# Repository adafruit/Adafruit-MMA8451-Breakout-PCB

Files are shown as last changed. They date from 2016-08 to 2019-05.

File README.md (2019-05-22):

## Adafruit MMA8451 Triple-Axis Accelerometer - ±2/4/8g @ 14-bit Breakout PCB
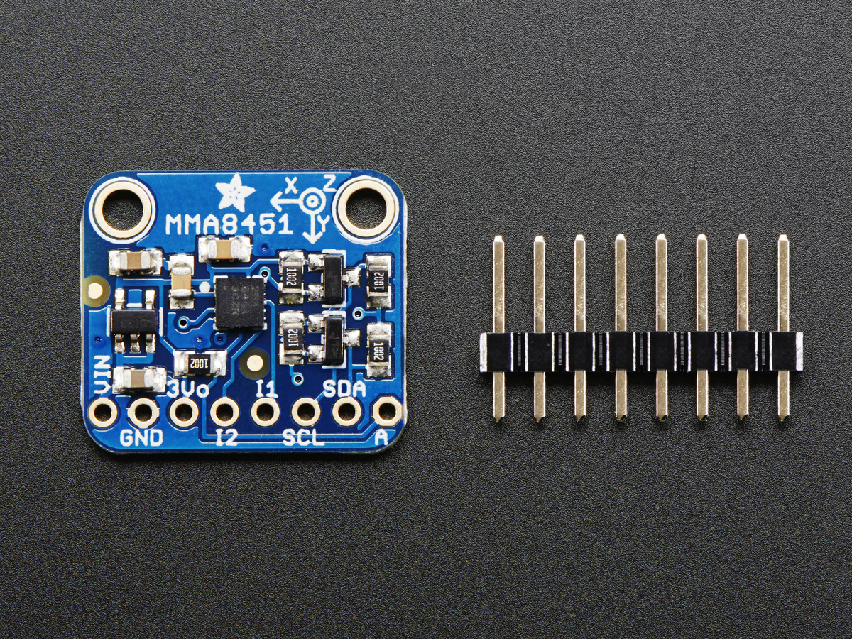
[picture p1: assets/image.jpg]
<a href="http://www.adafruit.com/products/2019"><br/>
Click here to purchase one from the Adafruit shop</a>

So many accelerometers and so little time! We've expanded our accelerometer selection even more with this high-precision and inexpensive MMA8451 Triple-Axis Accelerometer w/ 14-bit ADC. You can detect motion, tilt and basic orientation with a digital accelerometer - and the MMA8451 is a great accelerometer to start with. It has a wide usage range, from +-2g up to +-8g yet is easy to use with Arduino or another microcontroller

The MMA8451 is a miniature little accelerometer from Freescale, who are (by this point) masters at the accelerometer-design game. It's designed for use in phones, tablets, smart watches, and more, but works just as well in your Arduino project. Of the MMA8451/MMA8452/MMA8453 family, the MMA8451 is the most precise with a built in 14-bit ADC. The accelerometer also has built in tilt/orientation detection so it can tell you whether your project is being held in landscape or portrait mode, and whether it is tilted forward or back

PCB files for the Adafruit MMA8451 Breakout. The format is EagleCAD schematic and board layout
- https://www.adafruit.com/product/2019

### License

Adafruit invests time and resources providing this open source design, please support Adafruit and open-source hardware by purchasing products from [Adafruit](https://www.adafruit.com)!

All text above must be included in any redistribution

Designed by Limor Fried/Ladyada for Adafruit Industries.
Creative Commons Attribution/Share-Alike, all text above must be included in any redistribution. 
See license.txt for additional information.

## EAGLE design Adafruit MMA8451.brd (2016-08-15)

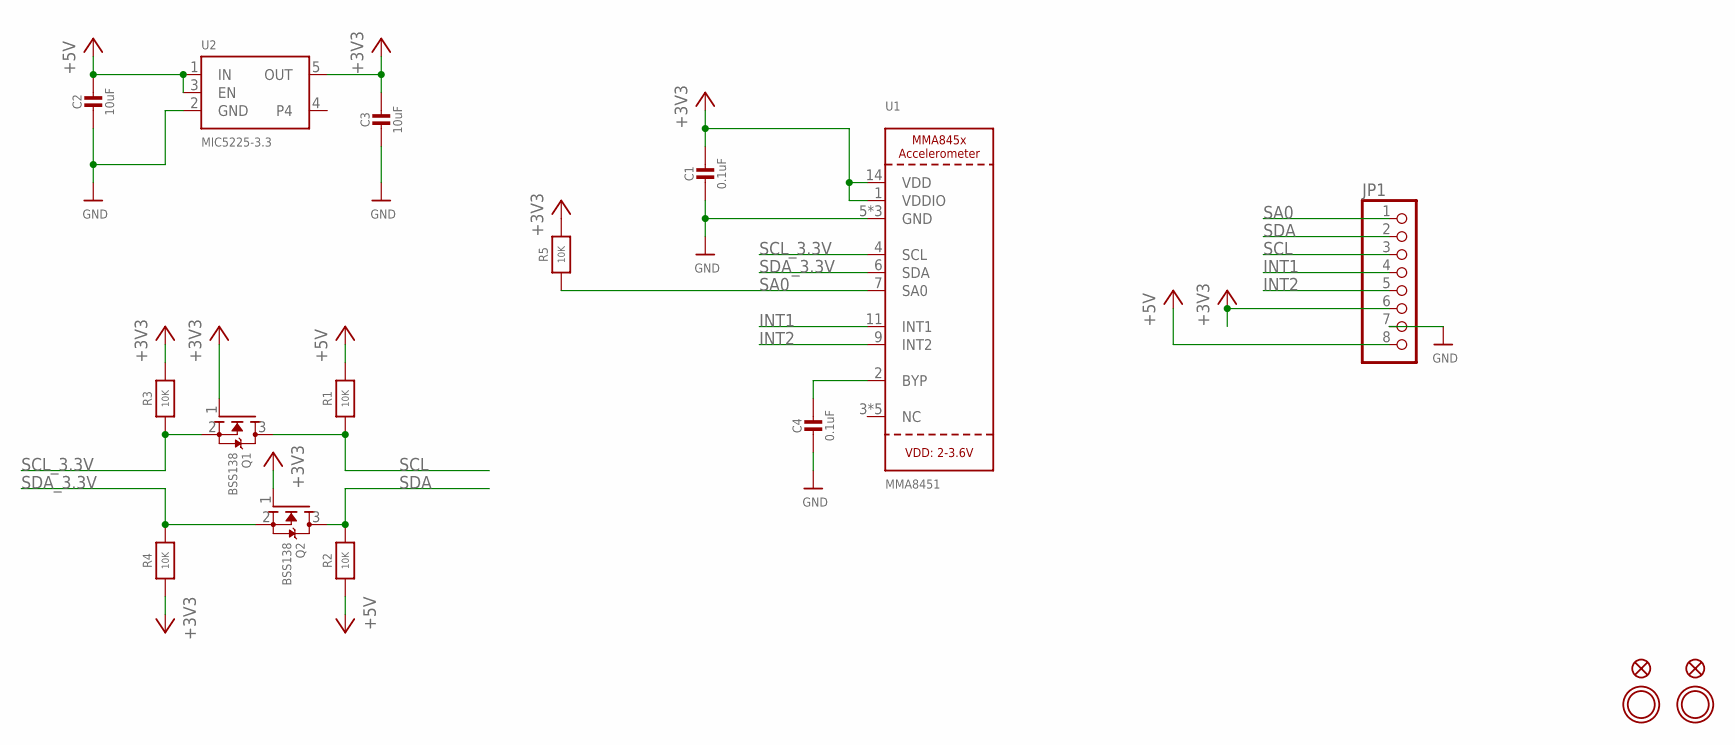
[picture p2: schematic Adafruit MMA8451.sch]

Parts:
C1: 0.1uF; 0805-NO
C2, C3: 10uF; 0805-NO
C4: 0.1uF; 0805_10MGAP
FID1, FID2: FIDUCIAL""; FIDUCIAL_1MM
JP1: HEADER-1X870MIL; 1X08_ROUND_70
Q1, Q2: BSS138; SOT23-WIDE
R1, R2, R3, R4, R5: 10K; 0805-NO
U1: MMA8451; MMA845X_QFN_16MM
U2: MIC5225-3.3; SOT23-5
U$3, U$6: MOUNTINGHOLE2.5; MOUNTINGHOLE_2.5_PLATED

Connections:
+3V3: C1.1, C3.1, JP1.6, Q1.1 (G), Q2.1 (G), R3.2, R4.1, R5.2, U1.1 (VDDIO), U1.14 (VDD), U2.5 (OUT)
GND: C1.2, C2.2, C3.2, C4.2, JP1.7, U1.5 (GND), U1.10 (GND), U1.12 (GND), U2.2 (GND)
INT1: JP1.4, U1.11 (INT1)
INT2: JP1.5, U1.9 (INT2)
unnamed: C4.1, U1.2 (BYP)
SA0: JP1.1, R5.1, U1.7 (SA0)
SCL: JP1.3, Q1.3 (D), R1.1
SCL_3.3V: Q1.2 (S), R3.1, U1.4 (SCL)
SDA: JP1.2, Q2.3 (D), R2.2
SDA_3.3V: Q2.2 (S), R4.2, U1.6 (SDA)
VIN: C2.1, JP1.8, R1.2, R2.1, U2.1 (IN), U2.3 (EN)

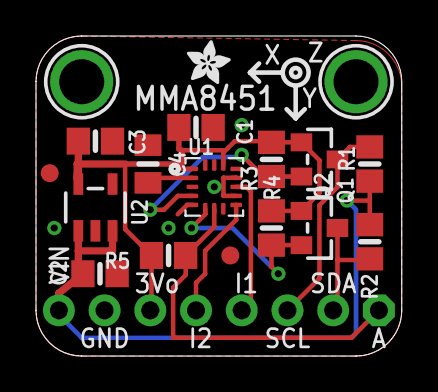
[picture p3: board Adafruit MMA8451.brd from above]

Board: 2 copper layers, 20.3 x 17.8 mm, 19 parts (0 on the bottom side), 11 nets.

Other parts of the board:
U$10: ADAFRUIT_2.5MM

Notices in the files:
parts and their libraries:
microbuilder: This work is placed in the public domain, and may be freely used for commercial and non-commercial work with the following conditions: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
